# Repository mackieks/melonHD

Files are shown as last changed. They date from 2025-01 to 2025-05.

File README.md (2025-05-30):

# melonHD 🍈

 ## Purchase melonHD on [Flashfi.re](https://flashfi.re)
 
 melonHD is a video converter module based around Lontium Semiconductor's LT6711A. It accepts an HDMI 2.0 input signal (up to 2160p) and outputs USB-C DisplayPort 1.2 Alt Mode. 

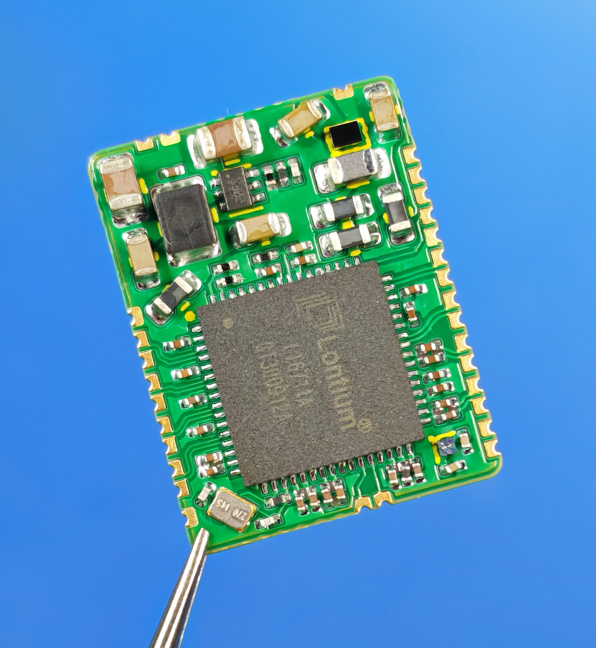
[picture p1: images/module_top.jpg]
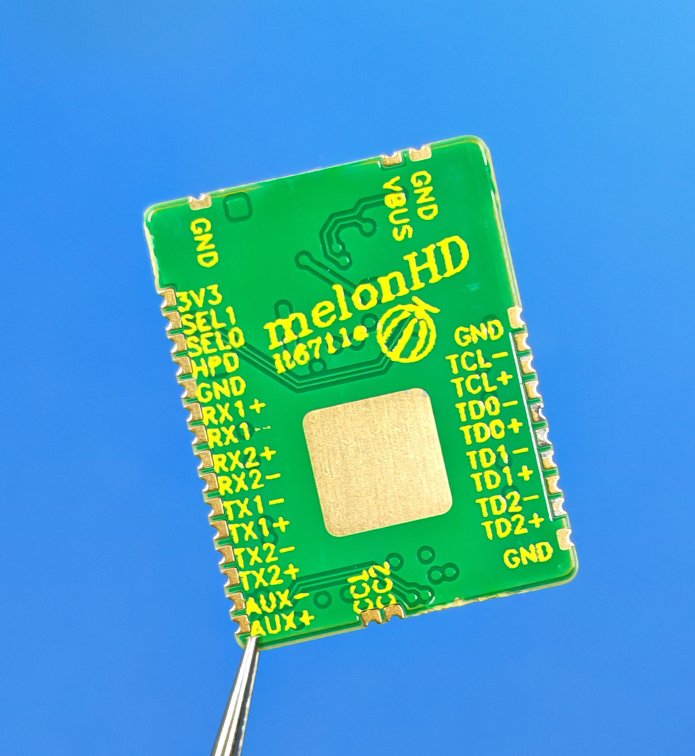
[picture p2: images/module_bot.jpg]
   

 The module is designed to allow [portablizers](https://bitbuilt.net/forums/index.php) to add USB-C video output to DIY handheld video game systems, and therefore does not expose the HDMI DDC connections. As such, compatibility with PCs and other HDMI sources which rely on EDID is not guaranteed. 
 
 For legal reasons, the melonHD module itself is not open source. This repository contains documentation, usage guidelines, and an open source carrier board reference design.

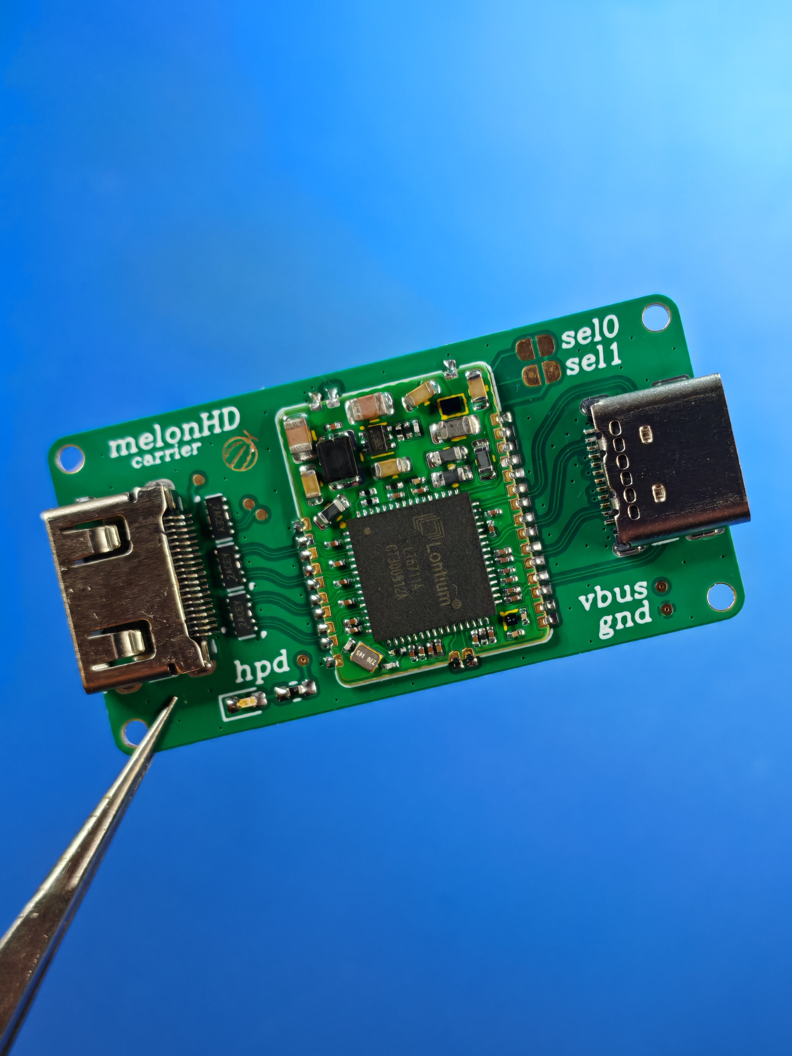
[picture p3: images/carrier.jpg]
 

 ## Features

- [x] Super compact 17 x 13mm 0.8mm-thick castellated PCB
- [x] 480p - 2160p HDMI 2.0 input and USB-C DP 1.2 Alt Mode output
- [x] Pin-strappable VBUS PDO selection: 5V/3A, 9V/3A, 12V/3A, or 15V/3A
- [x] Powered directly from 5V - 15V VBUS with onboard voltage regulators
- [x] HPD (hotplug detect) output pin: high for DP Alt Mode contracts, low for power-only contracts

 

## Usage

TODO

## License
Carrier board is licensed under Solderpad Hardware License v2.1

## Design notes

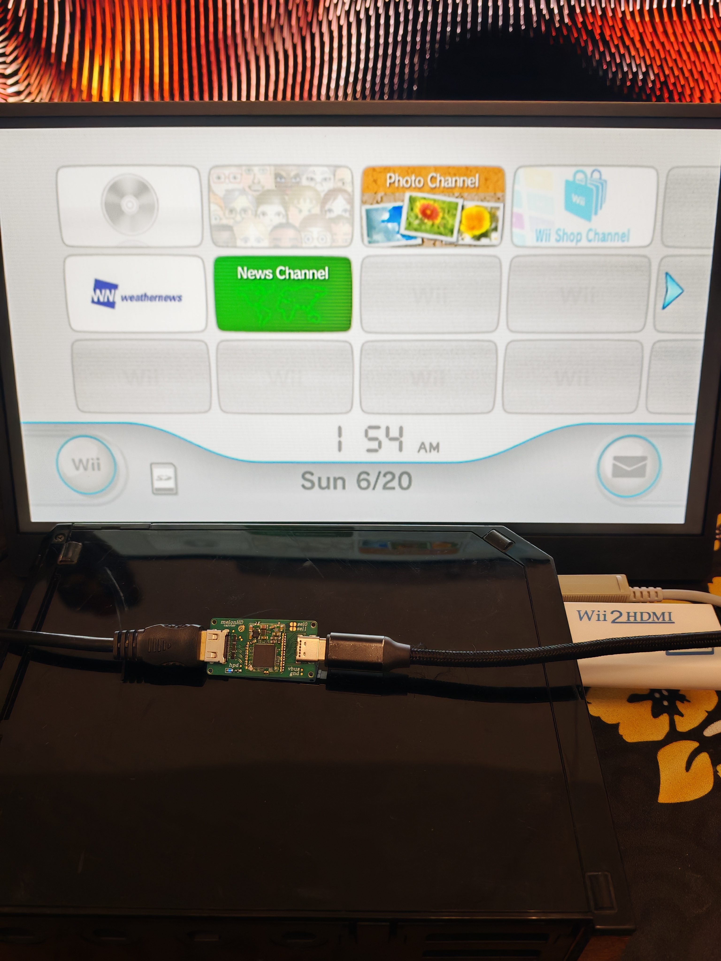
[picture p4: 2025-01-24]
images/wii.jpg

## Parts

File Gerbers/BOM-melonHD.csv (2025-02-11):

Comment | Designator | Footprint | LCSC | Quantity
1k | R1 | R_0603_1608Metric | C21190 | 1
green | D1 | LED_0603_1608Metric | C2286 | 1
ESD204DQAR-ES | U2,U3,U4 | Diodes_UDFN-10_1.0x2.5mm_P0.5mm | C2827646 | 3
XUNPU HDMI-201 or Würth 685119136923 | J2 | 685119136923 | C720618 | 1
XUNPU TYPEC-324G-BCP24 or GCT USB4080-03-A | J1 | GCT_USB4080-03-A_REVA1 | C920230 | 1

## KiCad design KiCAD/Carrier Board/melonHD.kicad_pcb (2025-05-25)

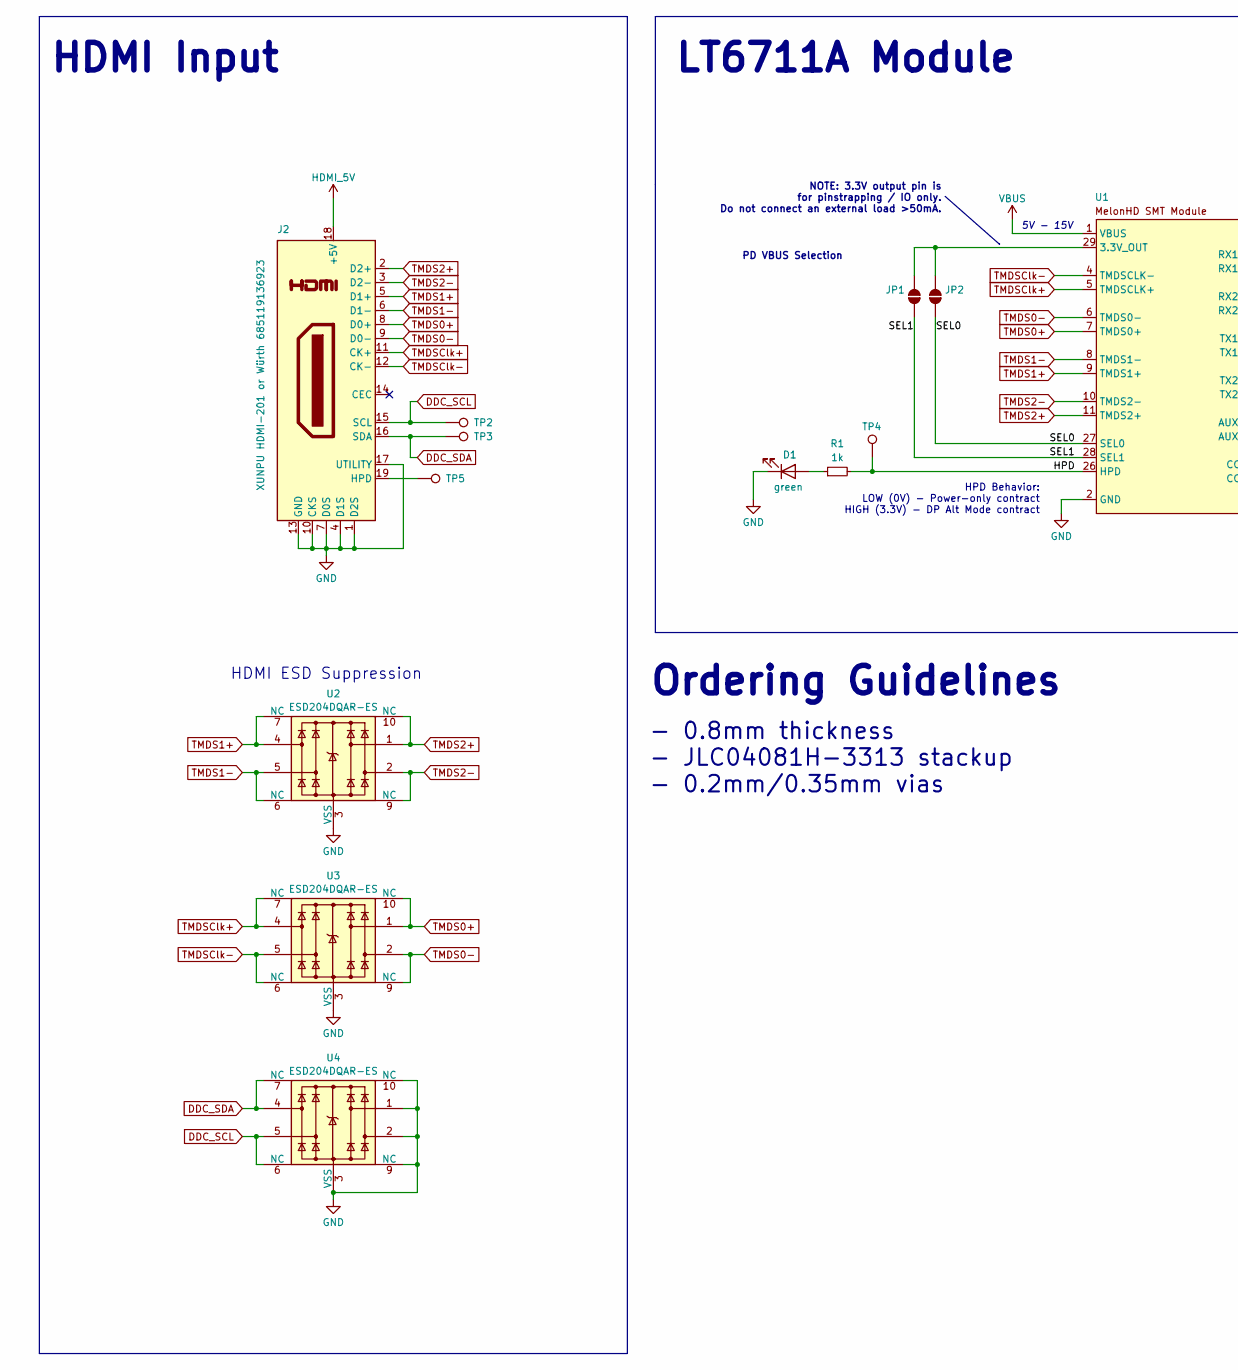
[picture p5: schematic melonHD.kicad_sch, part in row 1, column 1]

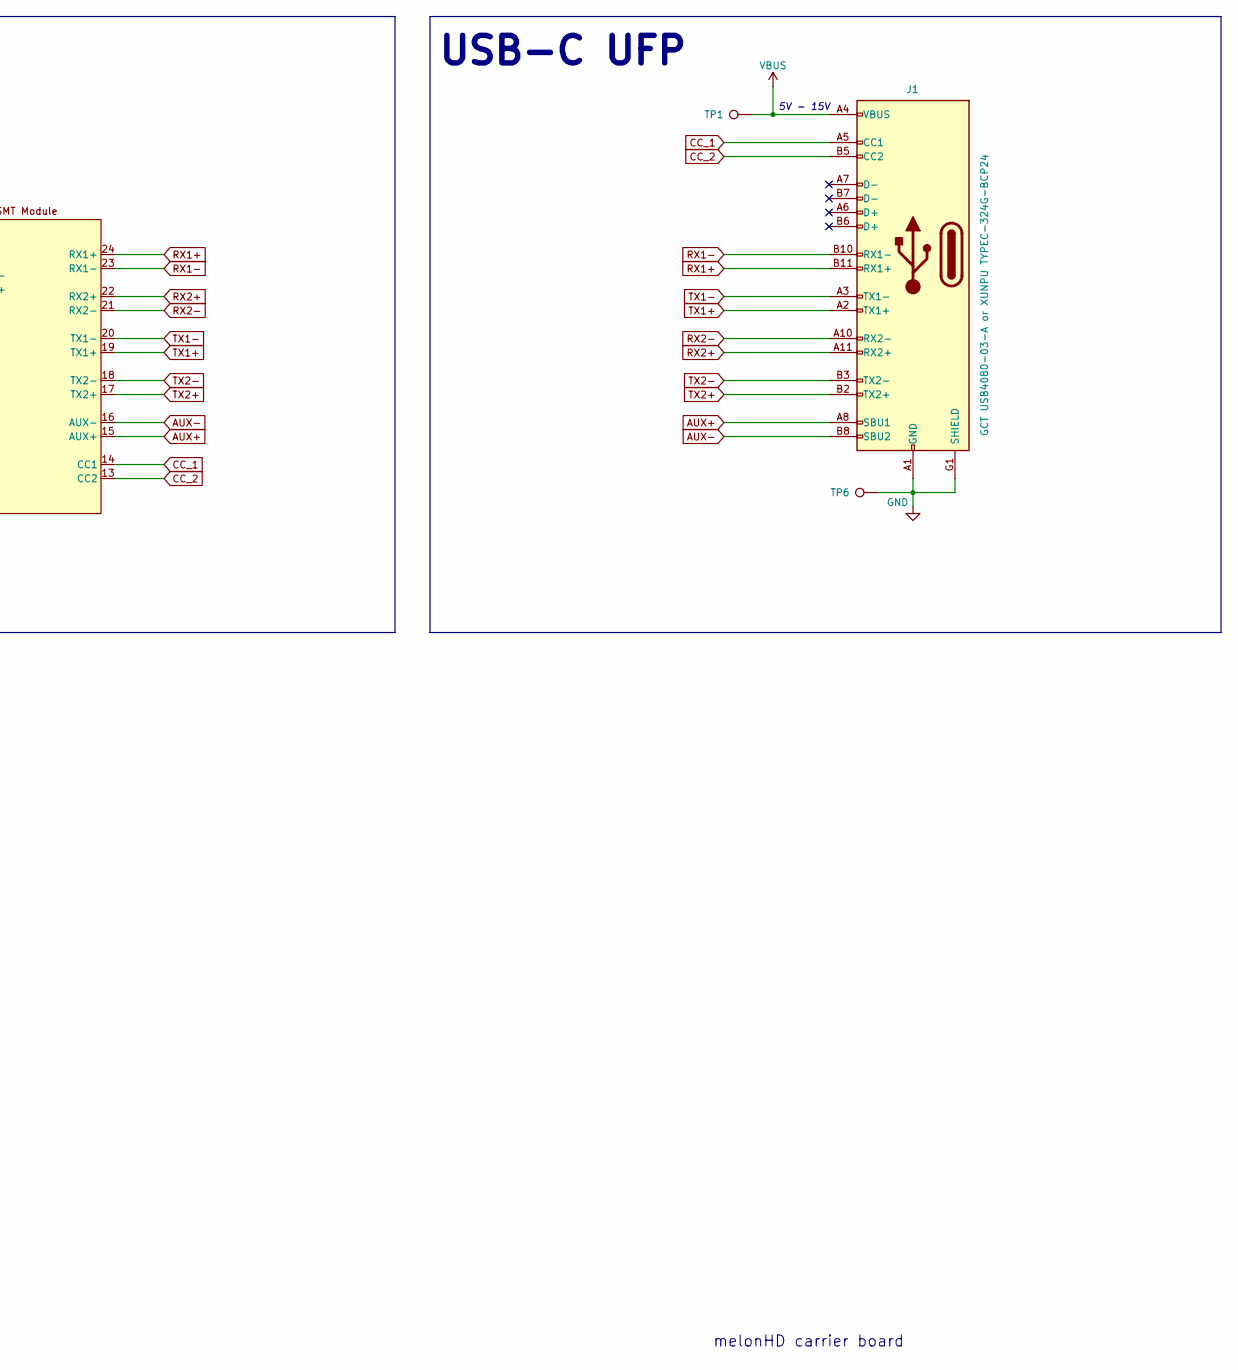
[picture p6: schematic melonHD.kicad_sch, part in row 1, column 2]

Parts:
D1: green; LED_0603_1608Metric
J1: GCT USB4080-03-A or XUNPU TYPEC-324G-BCP24; GCT_USB4080-03-A_REVA1
J2: XUNPU HDMI-201 or Würth 685119136923; 685119136923
JP1, JP2: SolderJumper_2_Open; SolderJumper-2_P1.3mm_Open_RoundedPad1.0x1.5mm
R1: 1k; R_0603_1608Metric
TP1, TP2, TP3, TP4, TP5, TP6: TestPoint; TestPoint_Pad_D0.75
U1: melonHD_SMT
U2, U3, U4: ESD204DQAR-ES; Diodes_UDFN-10_1.0x2.5mm_P0.5mm

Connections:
/HPD: R1.2, TP4.1, U1.26 (HPD)
/SEL0: JP2.1 (A), U1.27 (SEL0)
/SEL1: JP1.1 (A), U1.28 (SEL1)
AUX+: J1.A8 (SBU1), U1.15 (AUX+)
AUX-: J1.B8 (SBU2), U1.16 (AUX-)
CC_1: J1.A5 (CC1), U1.14 (CC1)
CC_2: J1.B5 (CC2), U1.13 (CC2)
DDC_SCL: J2.15 (SCL), TP2.1, U4.5, U4.6 (NC)
DDC_SDA: J2.16 (SDA), TP3.1, U4.4, U4.7 (NC)
GND: D1.1 (K), J1.1 (SHIELD), J1.A1 (GND), J1.A12 (GND), J1.B1 (GND), J1.B12 (GND), J1.G1 (SHIELD), J1.G2 (SHIELD), J1.G3 (SHIELD), J1.G4 (SHIELD), J2.1 (D2S), J2.4 (D1S), J2.7 (D0S), J2.10 (CKS), J2.13 (GND), J2.17 (UTILITY), J2.20 (GND), J2.21 (GND), J2.22 (GND), J2.23 (GND), TP6.1, U1.2 (GND), U1.3 (GND), U1.12 (GND), U1.25 (GND), U1.30 (GND), U1.31 (GND), U2.3 (VSS), U2.8 (VSS), U3.3 (VSS), U3.8 (VSS), U4.1, U4.2, U4.3 (VSS), U4.8 (VSS), U4.9 (NC), U4.10 (NC)
HDMI_5V: J2.18 (+5V)
unnamed: D1.2 (A), R1.1
unnamed: J2.19 (HPD), TP5.1
unnamed: JP1.2 (B), JP2.2 (B), U1.29 (3.3V_OUT)
RX1+: J1.B11 (RX1+), U1.24 (RX1+)
RX1-: J1.B10 (RX1-), U1.23 (RX1-)
RX2+: J1.A11 (RX2+), U1.22 (RX2+)
RX2-: J1.A10 (RX2-), U1.21 (RX2-)
TMDS0+: J2.8 (D0+), U1.7 (TMDS0+), U3.1, U3.10 (NC)
TMDS0-: J2.9 (D0-), U1.6 (TMDS0-), U3.2, U3.9 (NC)
TMDS1+: J2.5 (D1+), U1.9 (TMDS1+), U2.4, U2.7 (NC)
TMDS1-: J2.6 (D1-), U1.8 (TMDS1-), U2.5, U2.6 (NC)
TMDS2+: J2.2 (D2+), U1.11 (TMDS2+), U2.1, U2.10 (NC)
TMDS2-: J2.3 (D2-), U1.10 (TMDS2-), U2.2, U2.9 (NC)
TMDSClk+: J2.11 (CK+), U1.5 (TMDSCLK+), U3.4, U3.7 (NC)
TMDSClk-: J2.12 (CK-), U1.4 (TMDSCLK-), U3.5, U3.6 (NC)
TX1+: J1.A2 (TX1+), U1.19 (TX1+)
TX1-: J1.A3 (TX1-), U1.20 (TX1-)
TX2+: J1.B2 (TX2+), U1.17 (TX2+)
TX2-: J1.B3 (TX2-), U1.18 (TX2-)
VBUS: J1.A4 (VBUS), J1.A9 (VBUS), J1.B4 (VBUS), J1.B9 (VBUS), TP1.1, U1.1 (VBUS)

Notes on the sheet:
Ordering Guidelines
HDMI ESD Suppression
USB-C UFP
5V - 15V
- 0.8mm thickness - JLC04081H-3313 stackup - 0.2mm/0.35mm vias
HDMI Input
melonHD carrier board
LT6711A Module
NOTE: 3.3V output pin is for pinstrapping / IO only. Do not connect an external load >50mA.
PD VBUS Selection
HPD Behavior: LOW (0V) - Power-only contract HIGH (3.3V) - DP Alt Mode contract

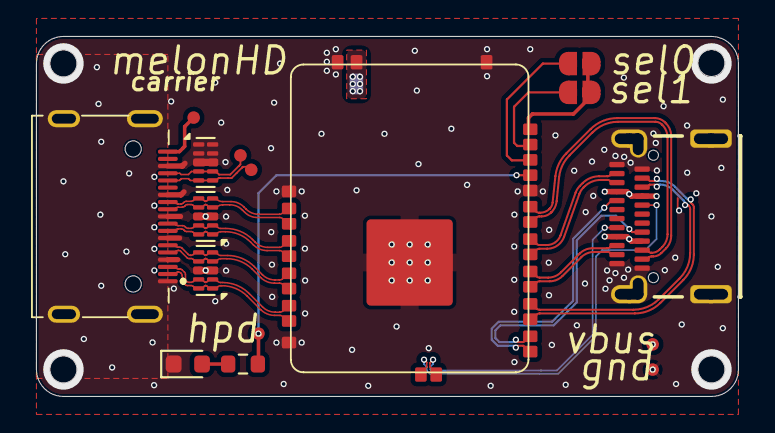
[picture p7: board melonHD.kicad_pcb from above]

Board: 4 copper layers, 39.0 x 20.0 mm, 16 parts (0 on the bottom side), 30 nets.

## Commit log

2025-01-24 add everything
    [melonHD.kicad_pcb, melonHD.kicad_sch]
2025-02-02 embed fonts + 3d
    [melonHD.kicad_pcb]
2025-02-11 Update carrier board
    [melonHD.kicad_pcb, melonHD.kicad_sch]
2025-02-11 Update schematic notes
    [melonHD.kicad_sch]
2025-02-11 Add gerbers + CPL + BOM
    [BOM-melonHD.csv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]
2025-05-25 Update module symbol
    [melonHD.kicad_sch]
2025-05-25 Update carrier board and fix 3D embed
    [melonHD-B_Cu.gbr, melonHD-B_Mask.gbr, melonHD-B_Silkscreen.gbr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]
